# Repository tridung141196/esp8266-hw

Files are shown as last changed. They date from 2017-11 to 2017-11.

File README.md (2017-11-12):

# esp8266_iotmaker

## Features

ESP8266 IOTMAKERVN:
- Size: 1.86x1 inch.
- Intergrate micro USB.
- Input Voltage: 5v (Vusb).
- Open hardware with CC-BY-SA license.
- Design with KiCad.

## Hardware

### Schematics

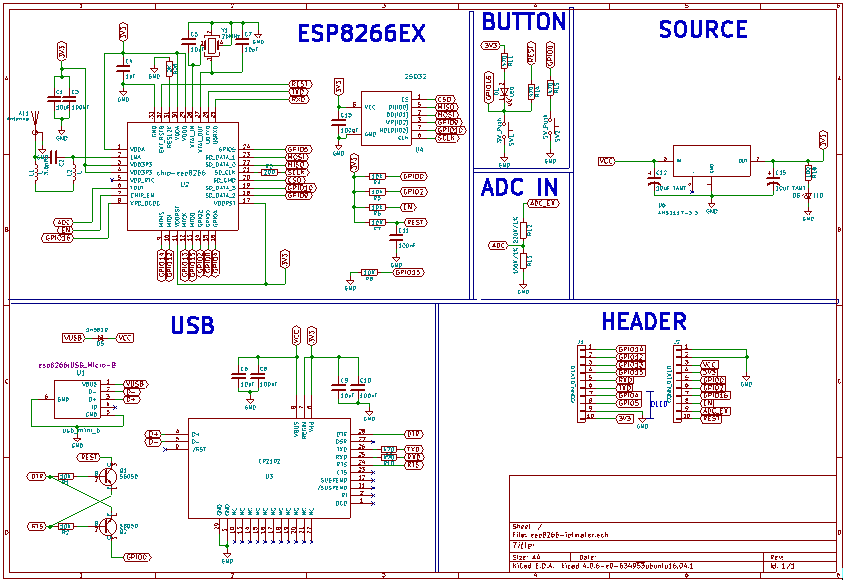
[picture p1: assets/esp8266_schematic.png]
IoT WiFi UNO Schematic


### PCB Layout

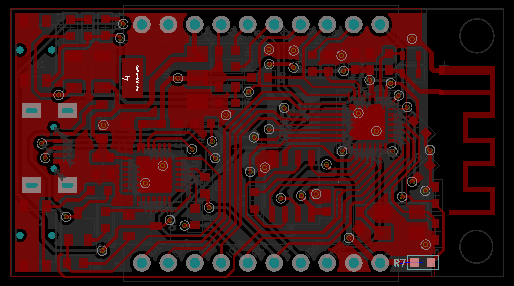
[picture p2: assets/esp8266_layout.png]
IoT WiFi UNO PCB


### 3D

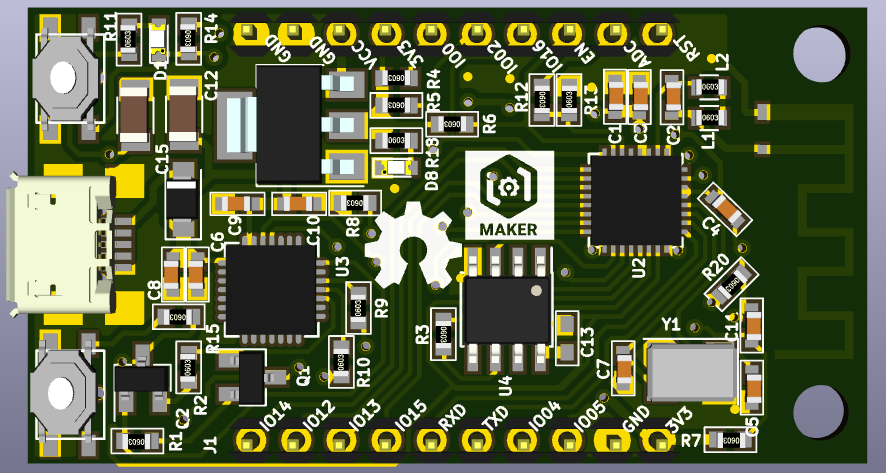
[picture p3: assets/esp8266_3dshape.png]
IoT WiFi UNO 3D


### Pinout 

### Fritzing part 

### Gerber

[Download](./assets/esp8266-1x1.86inch.zip)

### BOM 

| Designator | Package | Quantity | Designation  | Nơi bán  |
|---|---|---|---|---|
| U1 | USB_Micro-B | 1 | usb_mini_b |[thegioiic](http://thegioiic.com/products/microusb-fm-v2)|
| U2 | QFN-32-1EP_5x5mm_Pitch0.5mm | 1 | ESP8266ES | 						 |
| U3 | QFN-28-1EP_5x5mm_Pitch0.5mm | 1 | CP2102 |[thegioiic](http://thegioiic.com/products/cp2102) |
| U4 | SOIC-8_3.9x4.9mm_Pitch1.27mm | 1 | SLASH 4MB |[banlinhkien](http://banlinhkien.vn/goods-5796-w25q32fv-sop8-ic-flash-32mbit.html) |
| U6 | SOT-223 | 1 | AMS1117/3V3  |[thegioiic](http://thegioiic.com/products/ams1117-3-3v)  |
| D1,D8 | LED_0603 | 2 | LED_Blue |[thegioiic](http://thegioiic.com/products/bl-0603-led) |
| Y1 | Crystal_SMD_2016-4pin_2.0x1.6mm| 1 | 26MHz |[thegioiic](http://thegioiic.com/products/26mhz-crystal-c5032)|
| Q1,Q2 | SOT-23 | 2 | S8050 |[banlinhkien](http://banlinhkien.vn/goods-4708-s8050-sot23-trans-npn-0-5a-40v-smd-j3y-.html)|
| L1,L2 | L_0603 | 2 | |
| C1,C6,C9 | C_0603 | 3 | 10uF |[thegioiic](http://thegioiic.com/products/10uf-16v-0603-cap)|
| C3,C8,C10,C11,C13 | C_0603 | 5 | 100nF |[thegioiic](http://thegioiic.com/products/100nf-16v-0603-cap)|
| C5,C7 | C_0603 | 2 | 10pF |[thegioiic](http://thegioiic.com/products/10pf-50v-0603-cap)|
| C12,C15 | C_1206 | 2 | 10uF Tant |[lkbk](http://linhkienbachkhoa.com/san-pham/tu-tantalum-10uf-16v-1206-10-3ohm/)|
| C2 | C_0603 | 1 | 5,6pF |[thegioiic](http://thegioiic.com/products/6-8pf-50v-0603-cap)|
| R1,R2,R4,R5,R6,R7,R8 | R_0603 | 7 | 10K |[thegioiic](http://thegioiic.com/products/10k-ohm-0603-1)|
| R9,R10,R11,R14,R15 | R_0603 | 5 | 470R |[thegioiic](http://thegioiic.com/products/470-ohm-0603-1)|
| R12 | R_0603 | 1 | 220k/1% |[thegioiic](http://thegioiic.com/products/220k-ohm-0603-1)|
| R13 | R_0603 | 1 | 100k/1% |[thegioiic](http://thegioiic.com/products/100k-ohm-0603-1)|
| R3 | R_0603 | 1 | 220R |[thegioiic](http://thegioiic.com/products/220-ohm-0603-1)|
| R18 | R_0603 | 1 | 100R |[thegioiic](http://thegioiic.com/products/100-ohm-0603-1)|
| R20 | R_0603 | 1 | 2k |[thegioiic](http://thegioiic.com/products/2k-ohm-0603-1)|
| D5 | D_SOD-123 | 1 | 1N5819 |[banlinhkien](http://banlinhkien.vn/goods-5519-diode-s4-sod123-1n5819-sod123-.html)|
| SW1,SW2 | SWITCH SMD | 2 | TACTICLE SW  |[thegioiic](http://thegioiic.com/products/ts-1189e)|
| J1,J2 | Pin_Header_Straight_1x10 | 2 | CONN_01X10 |

### Remark

This project was in development phase - we will remove this remark after release

# License



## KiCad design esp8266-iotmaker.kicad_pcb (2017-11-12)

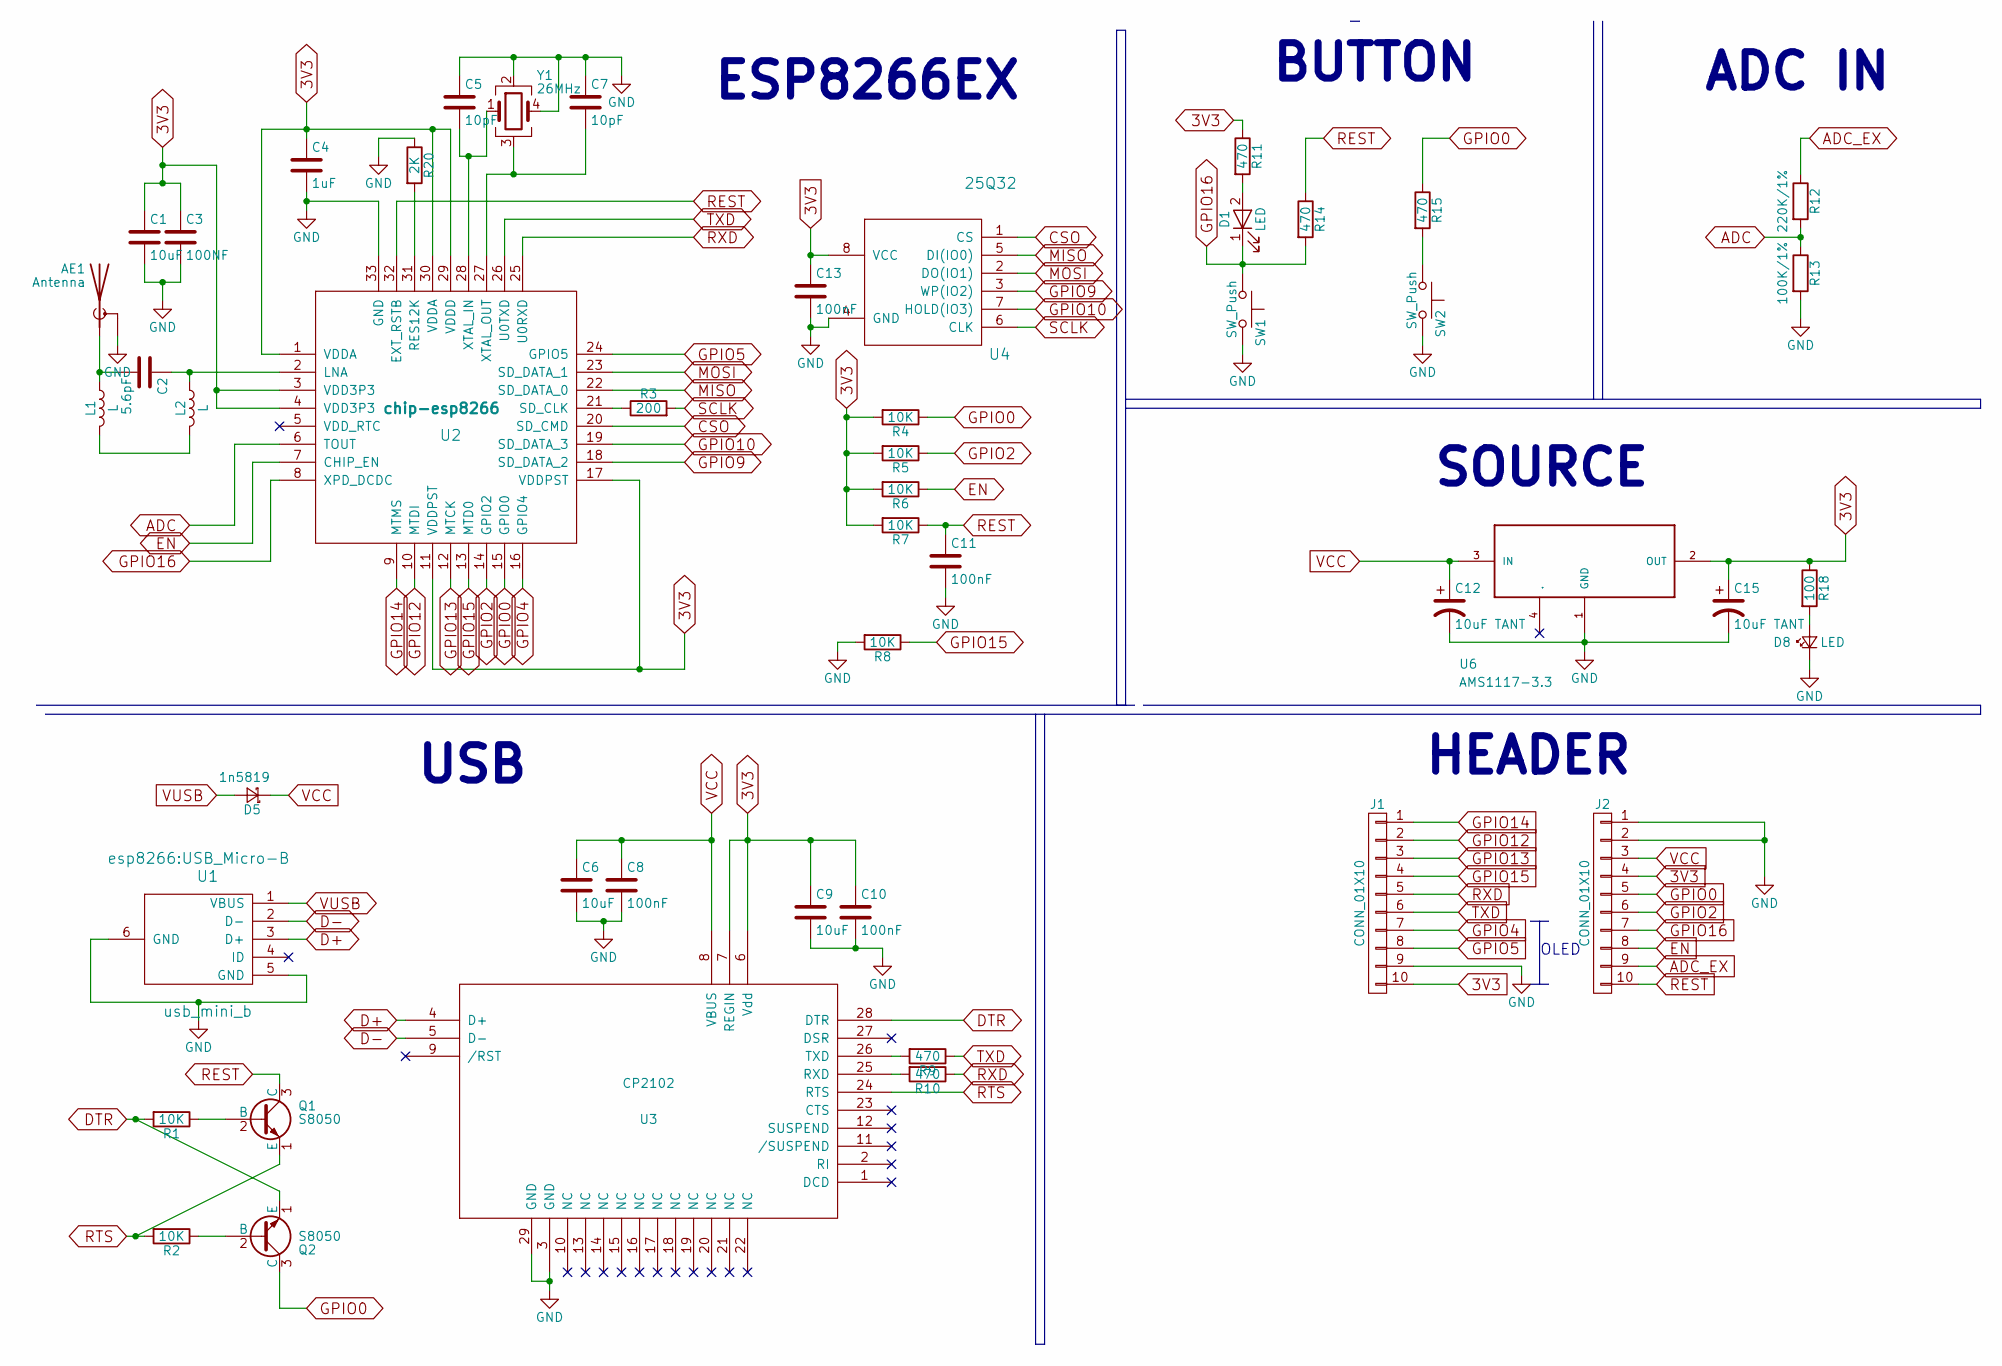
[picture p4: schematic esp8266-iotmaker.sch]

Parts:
AE1: Antenna; anten
C1, C6, C9: 10uF; C_0603
C2: 5.6pF; C_0603
C3: 100NF; C_0603
C4: 1uF; C_0603
C5, C7: 10pF; C_0603
C8, C10, C11, C13: 100nF; C_0603
C12, C15: 10uF TANT; C_1206
D1, D8: LED; LED_0603
D5: 1n5819; D_SOD-123
J1, J2: CONN_01X10; Pin_Header_Straight_1x10_Pitch2.54mm
L1, L2: L; L_0603
Q1, Q2: S8050; SOT-23_standar
R1, R2, R4, R5, R6, R7, R8: 10K; R_0603
R3: 200; R_0603
R9, R10, R11, R14, R15: 470; R_0603
R12: 220K/1%; R_0603
R13: 100K/1%; R_0603
R18: 100; R_0603
R20: 2K; R_0603
SW1, SW2: SW_Push; nut_nhan_ngang
U1: usb_mini_b; USB_Micro-B
U2: chip-esp8266; esp8266ex
U3: CP2102; cp2102
U4: 25Q32; SOIC-8_3.9x4.9mm_Pitch1.27mm
U6: AMS1117-3.3; SOT-223
Y1: 26MHz; Crystal_SMD_5032-4pin_5.0x3.2mm

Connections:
3V3: C1.1, C3.1, C4.1, C9.1, C10.1, C13.1, C15.1, J1.10, J2.4, R4.2, R5.2, R6.2, R7.2, R11.1, R18.1, U2.1 (VDDA), U2.3 (VDD3P3), U2.4 (VDD3P3), U2.11 (VDDPST), U2.17 (VDDPST), U2.29 (VDDD), U2.30 (VDDA), U3.6 (Vdd), U3.7 (REGIN), U4.8 (VCC), U6.2 (OUT)
ADC: R12.2, R13.1, U2.6 (TOUT)
ADC_EX: J2.9, R12.1
CSO: U2.20 (SD_CMD), U4.1 (CS)
D+: U1.3 (D+), U3.4 (D+)
D-: U1.2 (D-), U3.5 (D-)
DTR: Q2.1 (E), R1.2, U3.28 (DTR)
EN: J2.8, R6.1, U2.7 (CHIP_EN)
GND: AE1.2 (Shield), C1.2, C3.2, C4.2, C5.1, C6.2, C7.1, C8.2, C9.2, C10.2, C11.2, C12.2, C13.2, C15.2, D8.1 (K), J1.9, J2.1, J2.2, R8.2, R13.2, R20.1, SW1.2, SW2.2, U1.5 (GND), U1.6 (GND), U2.33 (GND), U3.3 (GND), U3.29 (GND), U4.4 (GND), U6.1 (GND), Y1.2, Y1.4; also elsewhere on the board
GPIO0: J2.5, Q2.3 (C), R4.1, R15.1, U2.15 (GPIO0)
GPIO2: J2.6, R5.1, U2.14 (GPIO2)
GPIO4: J1.7, U2.16 (GPIO4)
GPIO5: J1.8, U2.24 (GPIO5)
GPIO9: U2.18 (SD_DATA_2), U4.3 (WP(IO2))
GPIO10: U2.19 (SD_DATA_3), U4.7 (HOLD(IO3))
GPIO12: J1.2, U2.10 (MTDI)
GPIO13: J1.3, U2.12 (MTCK)
GPIO14: J1.1, U2.9 (MTMS)
GPIO15: J1.4, R8.1, U2.13 (MTD0)
GPIO16: D1.1 (K), J2.7, R14.2, SW1.1, U2.8 (XPD_DCDC)
MISO: U2.22 (SD_DATA_0), U4.5 (DI(IO0))
MOSI: U2.23 (SD_DATA_1), U4.2 (DO(IO1))
unnamed 22: AE1.1 (A), C2.2, L1.1; also elsewhere on the board
unnamed: C2.1, L2.1, U2.2 (LNA)
unnamed: C5.2, U2.28 (XTAL_IN), Y1.1
unnamed: C7.2, U2.27 (XTAL_OUT), Y1.3
unnamed: D1.2 (A), R11.2
unnamed: D8.2 (A), R18.2
unnamed: L1.2, L2.2
unnamed: Q1.2 (B), R1.1
unnamed: Q2.2 (B), R2.1
unnamed: R3.1, U2.21 (SD_CLK)
unnamed: R9.2, U3.26 (TXD)
unnamed: R10.2, U3.25 (RXD)
unnamed: R15.2, SW2.1
unnamed: R20.2, U2.31 (RES12K)
REST: C11.1, J2.10, Q1.3 (C), R7.1, R14.1, U2.32 (EXT_RSTB)
RTS: Q1.1 (E), R2.2, U3.24 (RTS)
RXD: J1.5, R10.1, U2.25 (U0RXD)
SCLK: R3.2, U4.6 (CLK)
TXD: J1.6, R9.1, U2.26 (U0TXD)
VCC: C6.1, C8.1, C12.1, D5.1 (K), J2.3, U3.8 (VBUS), U6.3 (IN)
VUSB: D5.2 (A), U1.1 (VBUS)

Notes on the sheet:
ESP8266EX
BUTTON
USB
SOURCE
HEADER
ADC IN
OLED

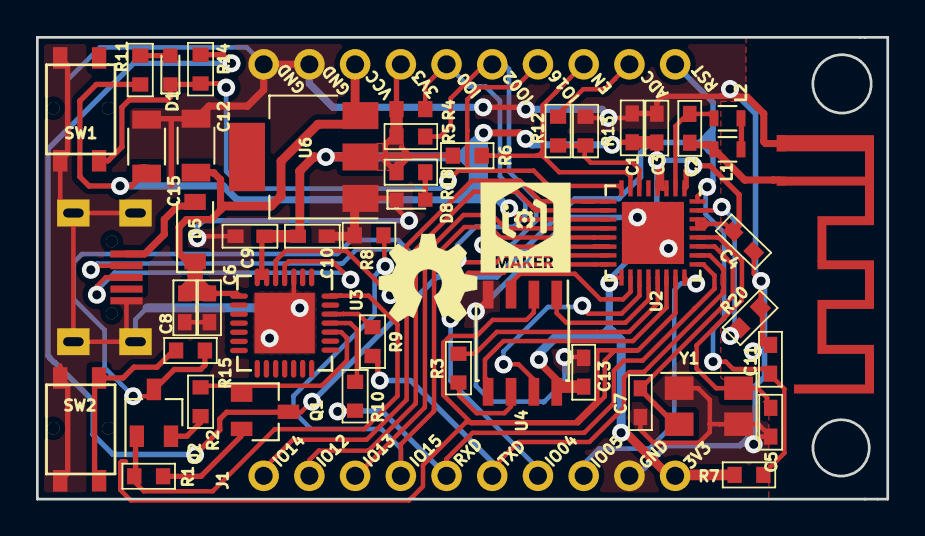
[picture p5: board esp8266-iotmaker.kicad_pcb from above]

Board: 2 copper layers, 47.2 x 25.7 mm, 49 parts (0 on the bottom side), 43 nets.

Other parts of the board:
ANT: ANT; anten

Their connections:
GND: ANT.2; also elsewhere on the board
unnamed 22: ANT.1; also elsewhere on the board

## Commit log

2017-10-24 set up kicad
    [esp8266-iotmaker.kicad_pcb, esp8266-iotmaker.sch]
2017-10-25 edit schematic
    [esp8266-iotmaker.sch]
2017-10-28 xap xep linh kien'
    [esp8266-iotmaker.kicad_pcb, esp8266-iotmaker.sch]
2017-10-28 add pcb
    [_saved_esp8266-iotmaker.sch, esp8266-iotmaker.kicad_pcb]
2017-10-30 update footprint
    [_saved_esp8266-iotmaker.sch, esp8266-iotmaker.kicad_pcb, esp8266-iotmaker.sch]
2017-10-30 add 3dshape
    [esp8266-iotmaker.kicad_pcb]
2017-11-01 complete pcb source
    [esp8266-iotmaker.kicad_pcb, esp8266-iotmaker.sch]
2017-11-03 xap xep linh kien
    [esp8266-iotmaker.kicad_pcb, esp8266-iotmaker.sch]
2017-11-04 complete pcb ver2.0
    [esp8266-iotmaker.kicad_pcb, esp8266-iotmaker.sch]
2017-11-05 add 3d and edit pcb
    [esp8266-iotmaker.kicad_pcb, esp8266-iotmaker.sch]
2017-11-05 edit readme
    [esp8266-iotmaker-B.Mask.gbs, esp8266-iotmaker-B.SilkS.gbo]
2017-11-05 edit solder mark
    [esp8266-iotmaker.kicad_pcb, esp8266-iotmaker.sch]
2017-11-11 edit pcb
    [esp8266-iotmaker.kicad_pcb]
2017-11-11 edit pcb with new crystal
    [_saved_esp8266-iotmaker.sch, esp8266-iotmaker.kicad_pcb]
2017-11-12 change footprint usb
    [esp8266-iotmaker.kicad_pcb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]

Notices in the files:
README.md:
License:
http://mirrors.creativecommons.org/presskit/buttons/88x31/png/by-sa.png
